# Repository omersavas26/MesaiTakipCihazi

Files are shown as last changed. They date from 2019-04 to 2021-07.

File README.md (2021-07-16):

# Mesai Takip Cihazı
## Kütahya İl Özel İdaresi - Bilgi işlem müdürlüğü

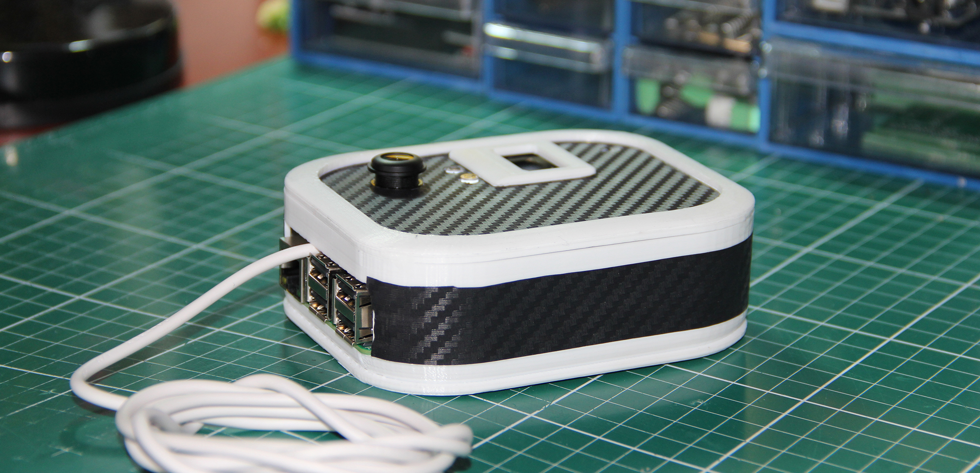
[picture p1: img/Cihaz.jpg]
Cihaz


Kütahya İl Özel İdaresi için geliştirmiş olduğumuz mesai takip cihazıdır. Yazılımı, devre tasarımı ve (3d yazdırılabilir) kutu tasarımı tamamen bize aittir. Tüm Raspberry Pi sürümleri ile çalışmaktadır. Fakat kutu RP3 için tasarlandığından diğer sürümleri için revizyon gerekir.

Cihazın açılması ile "main.py" yazılımı çalışır ve kart okutulması için beklemeye başlar. Başlatılması esnasında "./auth.py" dosyasını ve "./updateUsersList.py" dosyasını tetikleyerek cihaza özel güncel bir yetki alımasını ve bu yetkiyi kullanarak güncel kullanıcı listesinin alınmasını tetikler. Kullanıcı listesi personelin sunucu iletişimi esnasında bekletilmemesini sağlar. Personel kart okuttuğunda ilk olarak kameradan fotoğrafını alır, sonra ses ve ışık ile sinyal verir. Eğer okutulan kart id numarası "./file/users.json" dosyasında (bkz: "updateUserList.py") kayıtlı ise ekrana personel ismini yazar ver personeli bekletmeden gönderir. Sonra asenkron olarak sunucuya kart okutma bilgisini içeren bir istek atar cevap olarak da bir id numarası bekler. Cevap alabilirse çektiği fotoğrafın adını bu id bilgisi ile değiştirir. Eğer okutulan kart id numarası "./file/users.json" dosyasında yok ise sunucuya senkron bir istek atarak kart okutulma bilgisini gönderir cevap olarak de personel adı ve kart okutma için bir id numarası bekler. Beklediği cevap gelirse çektiği resmin adını yine id numarası ile değiştirerek personel adını ekrana yazdırır. Her ihtimal için; eğer beklenen cevap gelmez ise resmin adını card id ve tarih saat bilgisi olarak bırakır (bkz: "send.py"). Bir sonraki personelin kart okutmasını beklemeye başlar.

Eğer istenir ise, her kart okutmada bir kapı yada turnike tetiklenebilir. Ayrıca sunucu bağlantısı olmadan "./file/users.json" dosyasını manuel olarak doldurarak offline olarak da kullanılabilir.

Cihaz, personel geçişini yavaşlatmamak ve bağlantı olmadığı zamanlarda mesai takibini aksatmamak için çektği fotoğrafları önce hafızasında biriktirir sonra sizin belirlediğiniz peryotlarda sunucuya yüklemeye çalışır (bkz: "send.py"). Fotoğraflar "./foto" dizinindedir. İki tip fotoğraf vardır. İlki; sorunsuz bir şekilde sunucuya kart okutma bilgisi gönderilmiş ve cevap olarak da eklenen kaydın id bilgisi geri dönmüş olan fotoğraflar. Bunların isimleri "ID146589_XXXXX.jpg" şeklindedir. "_" karakterinden sonraki "XXXXXX" dizisi opsiyoneldir. Sunucu tarafından her kayıt için özel bir token gönderilir ise bu "XXXXXX" yerine yazılır. Böylelikle kayıt ikinci bir token ile korunmuş olur. Token bilgisini bilmeyen bir cihaz, fotoğraf yükleme yapamaz. İkinci tip fotoğraflar ise "TN198 76 64 27-2021_04_01_16_58_00.jpg" şeklinde isimlendirilmiştir. Bunlar, kart okutma bilgisi sunucuya gönderilememiş geçişler için çekilmiş olan fotoğraflardır. Adında kart bilgisi ve geçiş zamanını tutar. "send.py" yazılımı belirli peryotlarda çalışarak önce kayıt id 'leri olmayanları sunucuya kart okutma bilgisi oalrak gönderir ve id talep eder; ardından tüm fotoğrafları band genişliğini sınırlandırarak sunucuya yükler.

Sahadaki çok sayıda cihazınızın güncellenmesi için bir mekanizma kurulmuştur. Cihazlar belirli aralıklarda sizin belirdiğiniz adresi kontrol ederek güncel dosyaları otomatik olarak alabilirler (bkz "update.py"). İstenirse bu adres token ile korunabilir. Bu sayede yazılımın yanı sıra font ve logo gibi bilgilerde uzaktan değiştirilebilir.

Cihaz kameranın bir özelliği olarak 135 derece oval fotoğraf almaktadır. Ayrıca yine kameranın bir özelliği olarak karanlık ortamlarda da -gece görüşü- fotoğraf alabilmektedir. 13.56 Mhz mifare rfid kart ile uyumludur.

### auth.py
Eğer token auth ile çalışan bir servisiniz varsa bu dosya çalıştığında servisinize login isteği atar. Login olundu ise token ve cihaz ismi gibi bilgilerden "./file/auth.json" adında bir yetki dosyası oluşturur. "main.py" ve "send.py" gibi dosyalar ilk çalıştıklarında bu dosyayı tetikleyerek auth işlemi gerçekleştirirler ve çalışma süreleri boyunca auth.json dosyasını kullanırlar. Ayrıca cihaz ilk açıldığında da tetiklenir. Eğer cihaz yetkilendirmesi yapmak istenmiyorsa cihaz adı gibi bilgileri içeren sabit bir auth.json dosyası oluşturulabilir.

### clear.py
Cihaz ilk açıldığında çalışarak GPIO pin çıkışlarını temizler.

### control.py
cron ile her dakika çalışarak "main.py" nin çalışıyor olması gibi kontrol edilmesi gereken süreçleri izler. Sorun var ise yeniden başlatır.

### dateTimeSync.py 
Kısıtlı ağlarda cihaz tarih saat servisine erişierek zaman bilgisi alamaz ise bir http servis üzerinden tarih saat bilgisi alınarak cihazın zamanını günceller.

### fileList.txt
Bu dosya güncelleme sunucusu üzerinde bulunur. "update.py" yazılımı önce uzaktaki "version.txt" dosyasına sonra da bu dosyaya bakarak güncellemesi gereken dosyaları belirler ve güncel dosyaları indirerek cihaz üzerinde yazar. Yazılım mekanizmasına yeni bir dosya eklendi ise dosya adı ve yolu fileList.txt içine yazılmalıdır. 

### main.py
Ana yazılımdır. Cihaz ilk açıldığında çalışmaya başlar ve kapanana kadar çalışarak personelin kart okutmasını bekler. Kart okutulması ile fotoğraf çeker ve sunucu bu kart okutulması hakkında bilgilendirir. Başlatılması esnasında "./auth.py" dosyasını ve "./updateUsersList.py" dosyasını tetikleyerek cihaza özel güncel bir yetki alımasını ve (eğer gerekiyorsa) bu yetkiyi kullanarak güncel kullanıcı listesinin alınmasını tetikler.

### send.py
"./main.py" tarafından üretilmiş olan fotoğrafları belirli aralıklara sunucuya yüklemeye çalışır. Başlatılması esnasında "./auth.py" dosyasını tetikler ve (eğer gerekiyorsa) sunucu iletişimi sırasında bu yetki bilgisini kullanır.

### update.py
Belirli aralıklarla güncelleme sunucusuna talepler göndererek gülcel bir sürüm var ise cihaz yazılımını günceller.

### updateUserList.py
Sunucudan güncel kullanıcı bilgisini ister ve "./file/users.json" dosyasını doldurur. İstenirse users.json dosyası manuel olarak doldurularak cihaz offline olarak da kullanılabilir.

### version.txt
Aynı anda hem cihazda hemde güncelleme sunucusunda bulunur. "./update.py" bu dosyaya bakarak, sunucu üzerindeki dosyadan farklı ise güncelleme yapar.

### lib/helper.py
Tüm jenerik methodları içerir.

### lib/variables.py
Backend servisleri ve cihazın çalışması ile alakalı ayarları içeren dosyadır. Cihazı "senkron çalışmaya zorla" yada yemekhane gibi konumlarda kullanmak için "otantike olamayan kullanıcıya röleyi tetikleme" gibi ayarları yapabilmenizi sağlar. Ayarlarınız güncelleme gelse bile değişmesin isterseniz aynı dizine "localVariables.py" dosyası ile özel ayarlarınızı yazarsınız. 

### lib/test[*].py
Test scriptleri

## Bileşenler
 1. Raspberry Pi (3 B+ önerilir)
 2. Mikro SD kart
 3. Raspberry Pi Camera (Raspberry Pi 3 Model B + Night Vision Camera 5MP Wide Angle 135 Degree Fisheye Lens 1080P Camera Module)
 4. PCB Devre
 5. SSD 1306 Oled LCD ekran (128*64)
 6. RFID-RC522 rfid kart okuyucu
 7. Kırmızı ve yeşil kesik baş led
 8. 5V mini usb adaptor ve kablo
 9. Tek kanal 5v röle kartı (Opsiyonel)
 10. 3D yazdırılmış kutu parçaları
 11. Kaplama için yeteri kadar karbon folyo (Opsiyonel)
 12. 4 adet 2.2x6 mm ve 3 adet 2.2x9 mm vida
 13. 13x2, 4x1, 8x1 dişi header 
 14. Buzzer

## Donanım

[Video gelecek]

## Yazılım

1. Image ile kurulum
.img dosyası indirilip micro sd karta "Win32 Disk Imager" yada benzeri bir uygulama ile yazılıp 

2. Manuel kurulum
   - Arduino klasorundeki buzzer.ino dosyası Arduino nanoya upload edilir.
   - Raspbian işletim sistemi sd karta yüklenir ve açılır
   - `sudo raspi-config` ile ayar ekranı açılıp  ssh, camera, i2c ve spi aktifleştirilir
   - Aşağıdaki kurulumlar yapılır.
   
    ```
    sudo apt-get update
    sudo apt-get upgrade

    sudo apt-get install git python3 python3-spidev python3-dev python3-pip python3-smbus  python3-picamera i2c-tools wondershaper libopenjp2-7 -y
	
	sudo python3 -m pip install -U pip
	sudo python3 -m pip install -U setuptools
	
	sudo pip3 install Pillow
	sudo pip3 install adafruit-circuitpython-ssd1306
	sudo pip3 install requests
	
    sudo chmod 777 -R /var/www/html/
	
	git clone https://github.com/lthiery/SPI-Py.git && cd SPI-Py && git checkout 8cce26b9ee6e69eb041e9d5665944b88688fca68 && sudo python3 setup.py install	
    ```
	
   - `sudo crontab -e` ile zamanlanmış görevler açılıp en alta aşağıdaki satırlar eklenir.
   .
    ```	
	@reboot python3 /var/www/html/clear.py &

	@reboot python3 /var/www/html/dateTimeSync.py &
	0 * * * * python3 /var/www/html/dateTimeSync.py &

	@reboot sleep 10 && python3 /var/www/html/main.py

	0 */2 * * * python3 /var/www/html/send.py &

	0 12 * * * python3 /var/www/html/update.py

	0 13 * * * python3 /var/www/html/updateUsersList.py &

	* * * * * python3 /var/www/html/control.py &

	30 22 * * *     /sbin/shutdown -r +1 &
    ```
	
   - wget download.sh && ./download.sh 

## Yapılacaklar

1. Versiyon 3 'de oled arduino ile sürülecek, bu sayede raspberry pi açılana kadar ekranda bilgi mesajı basılacak.
2. Arduino nano yerine arduino mikro kullanılacak
3. Anlık enerji düşmesini engellemek için kondansatör koyulacak

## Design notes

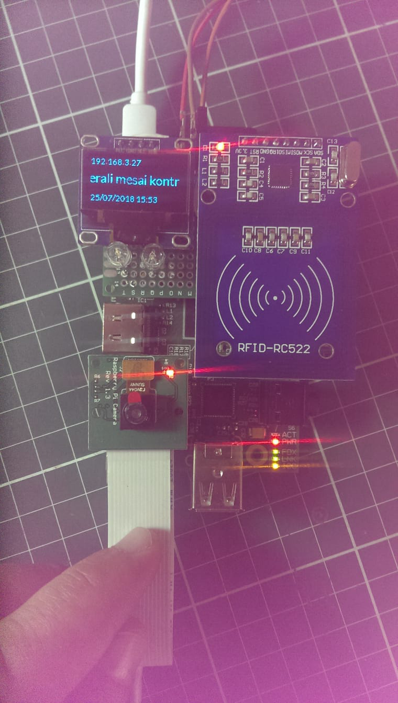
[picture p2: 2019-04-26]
img/Tasarım.jpeg

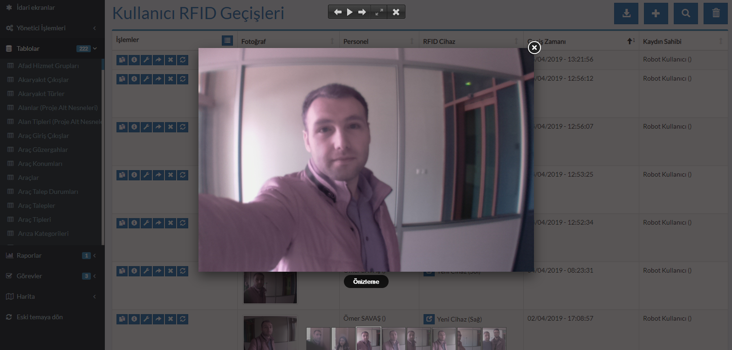
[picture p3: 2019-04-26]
img/Fotograf.png

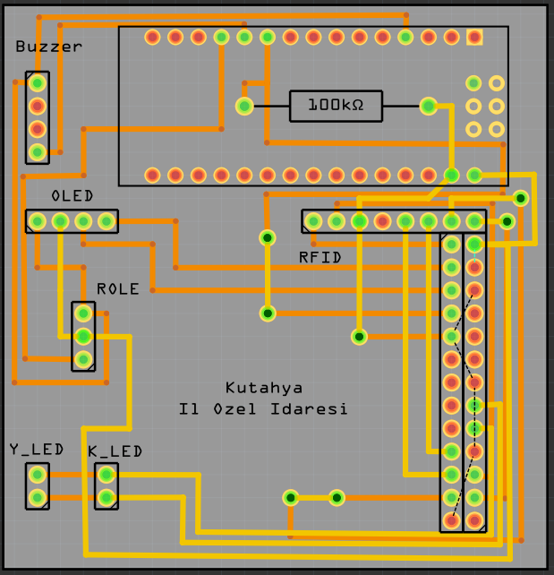
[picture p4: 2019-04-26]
circuit/devre.png

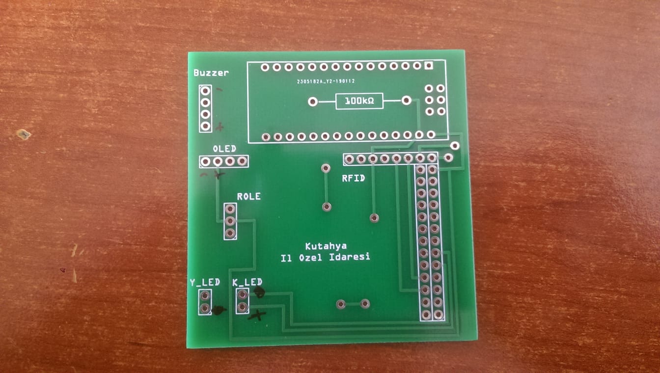
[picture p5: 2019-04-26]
circuit/Pcb.jpeg

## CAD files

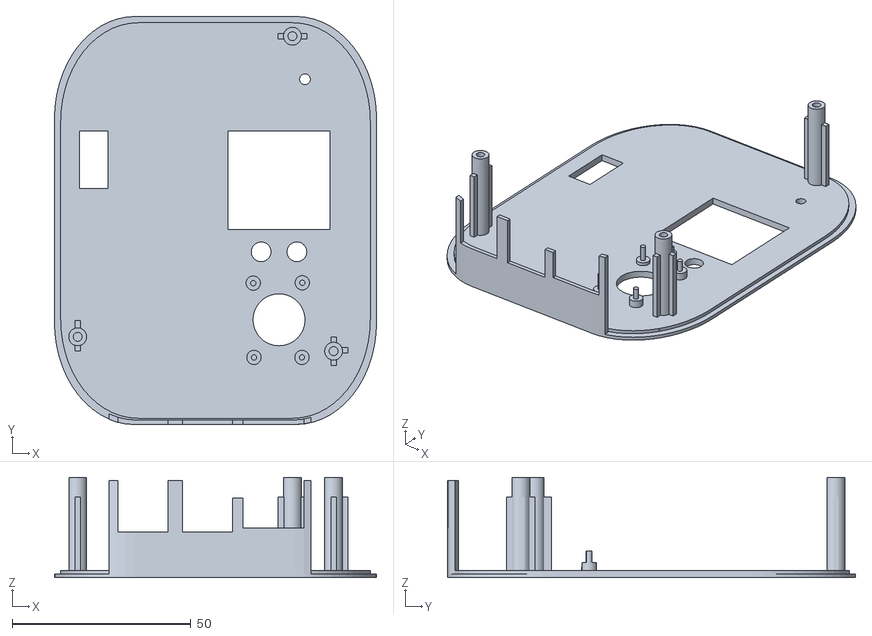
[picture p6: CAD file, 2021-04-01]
box/cover.stl
90.0 x 114.0 x 28.0

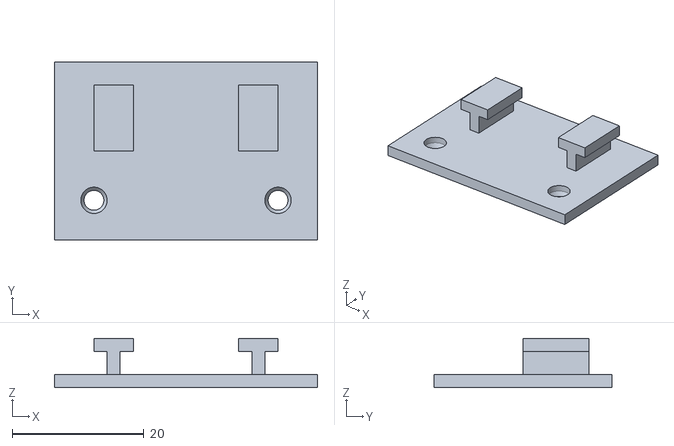
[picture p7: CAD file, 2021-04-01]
box/suspension.stl
40.0 x 27.0 x 7.50

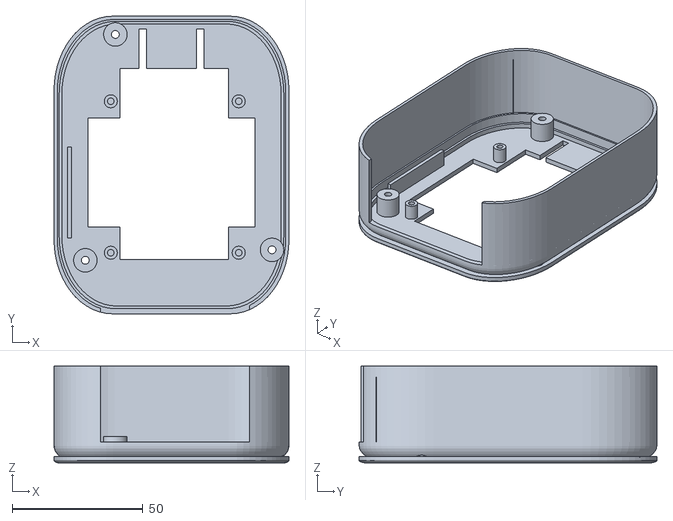
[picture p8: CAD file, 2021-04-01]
box/box.stl
90.0 x 114.0 x 37.0

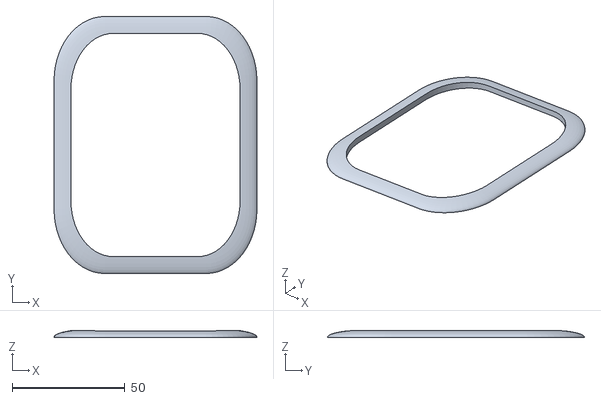
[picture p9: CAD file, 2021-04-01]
box/frame.stl
90.0 x 114.0 x 3.22

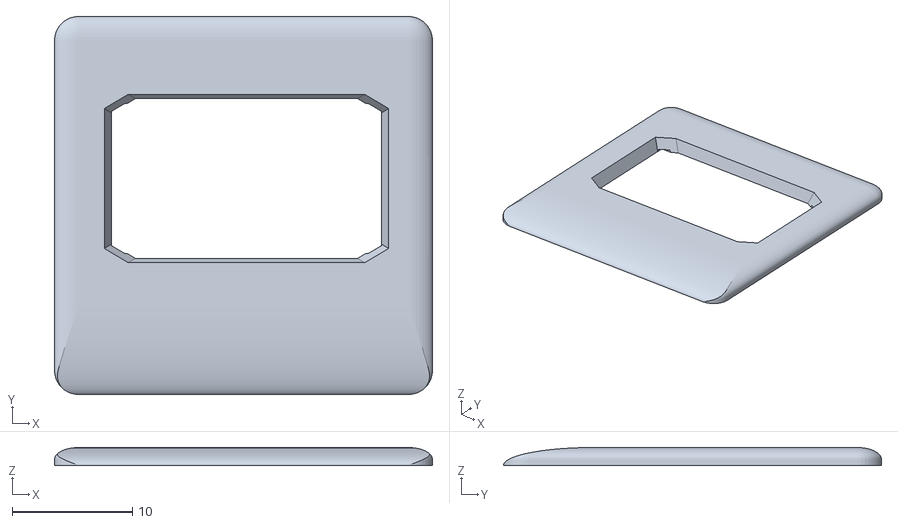
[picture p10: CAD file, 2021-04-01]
box/window.stl
31.5 x 31.5 x 1.50

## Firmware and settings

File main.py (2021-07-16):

##@reboot sleep 10 && python3 /var/www/html/main.py & 
##2021-07-16 12:00:00

import os 
import sys
import time
import datetime
import traceback

import RPi.GPIO as GPIO

sys.path.append("/var/www/html/lib/")
from helper import *
import helper as h

file_name = os.path.basename(__file__)



buzzer_pin = 4 #buzzer_pin = 7  //7. bacak GPIO4
red_led = 23#red_led = 16
green_led = 24#green_led = 18
triger_pin = 17#triger_pin = 11

display_scene_timer_period = 15.0
display_using = False
current_scene = -1
scenes = []

read_rfid_timer_period = 0.25	
local_last_rfid_card_id = ""

last_rfid_card_id_remember_timeout = 75.0
local_debug = False

sendPhotoForever = False

tanimsiz_kullanici_ad = "Tan\u0131ms\u0131z"
tanimsiz_kullanici_soyad = "Kullan\u0131c\u0131"

try:
	def clear_pins():
		global buzzer_pin, red_led, green_led, triger_pin
		
		pin_off(buzzer_pin)
		pin_off(red_led)
		pin_off(green_led)
		pin_off(triger_pin)
		
	def on_load():
		log_and_run(write_logo_on_display)
		
		log_and_run(clear_pins)
		
		log_and_run(set_cam)		
		
		temp = log_and_run(fill_auth, True)
		if temp == True:
			temp = log_and_run(fill_users, True)
		else:
			log_and_run(fill_users)
		
		if temp == False:
			log(INFO, "Users or Auth was failed")
			h.connected = False
		else:		
			h.connected = True
			
		log_and_run(connection_control)
		
		log_and_run(fill_scene)
		
	def set_cam():
		h.camera.rotation = 90
		h.camera.resolution = (1024, 768)
		
	def fill_scene():
		global scenes
		
		scenes.append(scene_1)
		scenes.append(scene_2)
		scenes.append(scene_3)
		scenes.append(logo_scene)
		
	def logo_scene():
		global current_scene, display_using
		control_index = 3
		seq = -1
		
		while True:
			if h.loop == False:
				break;
				
			if current_scene != control_index:
				break;
			
			waited = False 
			
			while display_using:
				log(INFO, "Display using.")
				waited = True
				time.sleep(1)
			
			if waited:
				log_and_run(clear_display)
			
			if seq != h.display_clear_seq:
				seq = h.display_clear_seq
				
				log_and_run(write_logo_on_display)
			
			time.sleep(0.3)
		
		
	def get_now_info_for_display():
		now = datetime.datetime.now()
			
		temp = str(now.strftime("%d aaa %H:%M:%S"));
		temp = temp.replace("aaa", h.months[now.month-1])
		
		temp = temp.split(" ")
		
		d = temp[0]+" "+temp[1]
		t = temp[2]
		return (d, t)
		
	def place_holder_date_time(params = None):
		
		if params == None:
			(d, t) = log_and_run(get_now_info_for_display)
			params = {
				"d": d,
				"t": t
			}
		
		write_text_on_display(params["d"], font_size = 16)
		write_text_on_display(params["t"], x=87, font_size = 16)
		
		return params
		
		
		
	def place_holder_auth_name(params = None):		
		if params == None:
		
			if h.auth == None:
				text = "Yetkisiz Cihaz - Yetkisiz Cihaz ";
			else:
				text = h.auth["name"] + " - " + h.auth["name"]
			
			params = {
				"sizes": [0, 0, 0, 0],
				"text": text,
				"current_x": 10
			}
			
		clean_area_on_display(params["sizes"])
		params["sizes"] = write_text_on_display(params["text"], x = params["current_x"], y = 22, font_size = 36)
		
		params["current_x"] = params["current_x"] - 7
		
		return params		
		
		
	def scene_1(current_x = 10):	
		scene_base(0, False, place_holder_date_time, place_holder_auth_name, 0.05)
		
	def get_real_local_ip():
		ips = get_ip_adresses()
		
		ip = "-"
		for i in range(len(ips)):
			if ips[i].find("127.0") > -1:
				continue
				
			ip = ips[i]
			break
			
		return ip
				
	def place_holder_no_connection(params = None):
		global oled_data
				
		ip = log_and_run(get_real_local_ip) 
		
		write_text_on_display("Internet", x = 18, y = 0, font_size = 24)
		write_text_on_display("Yok", x=42, y=25, font_size = 22)		
		write_text_on_center_of_display(ip, y = 48, font_size = 16)
	
	def scene_2():	
		scene_base(1, h.connected, place_holder_no_connection)
		
	def place_holder_no_auth(params = None):
		write_text_on_display("Yetkisiz", x = 10, y = 5, font_size = 28)
		write_text_on_display("Cihaz", x=25, y=32, font_size = 28)

	def scene_3():		
		scene_base(2, h.auth != None, place_holder_no_auth)
		
		
	def scene_base(control_index, next_scene_control, writing_function_on_clear, writing_function_forewer = None, loop_period = 0.3):
		global current_scene, display_using, local_debug
		
		if next_scene_control:
			current_scene = current_scene + 1
			if current_scene == len(scenes):
				current_scene = 0
				
			log_and_run_async(scenes[current_scene])	
			return
		
		seq = -1
				
		h.debug = False
		params1 = None
		params2 = None
		while True:
			if h.loop == False:
				break;
				
			if current_scene != control_index:
				break;
			
			waited = False 
			
			while display_using:
				log(INFO, "Display using")
				waited = True
				time.sleep(1)
			
			if waited:
				log_and_run(clear_display)
			
			if seq != h.display_clear_seq:
				seq = h.display_clear_seq
				
				params1 = log_and_run(writing_function_on_clear, params1)
				
			if writing_function_forewer != None:
				params2 = log_and_run(writing_function_forewer, params2)
			
			time.sleep(loop_period)
			
		h.debug = local_debug
			
	def run():
		log_and_run_async(update_display_scene)
		
		log_and_run(read_rfid)
		
	def update_display_scene():
		global display_scene_timer_period, current_scene, scenes, display_using
		
		temp = threading.Timer(display_scene_timer_period, update_display_scene)
		temp.daemon = True
		temp.start()
				
		current_scene = current_scene + 1
		if current_scene == len(scenes):
			current_scene = 0
				
		try:
			while display_using:
				log(INFO, "Display using..")
				time.sleep(0.3)
				
			log_and_run(clear_display)
			log_and_run(scenes[current_scene])
		except Exception as e:
			log_e(e, "update_display_scene error")
				
	def wait_message():
		log_and_run(clear_display)
		write_text_on_display("Bekleyin...", x=0, y=22, font_size = 26)
		
	def show_rfid_same_card_message_on_display():
		global red_led, display_using
		
		display_using = True		
		time.sleep(0.3)
		
		pin_on(red_led, time_out = 1)		
		pin_on(buzzer_pin, time_out = 0.05)
		
		log_and_run(clear_display)
				
		write_text_on_display("Bu kart", x = 24, y = 0, font_size = 22)
		write_text_on_display("az once", x = 24, y = 21, font_size = 22)
		write_text_on_display("okutldu!", x = 20, y = 42, font_size = 22)
		
		time.sleep(1)
		
		display_using = False

	def show_ip_on_display():
		global display_using 
		
		display_using = True
		time.sleep(0.3)
		
		ip = log_and_run(get_real_local_ip) 
		log_and_run(clear_display)
		write_text_on_center_of_display(ip, font_size = 16, direction = "xy")
		time.sleep(5);
		
		display_using = False
		
	def toggle_send_photo_forever():
		global sendPhotoForever, display_using
		
		display_using = True
		time.sleep(0.3)
		
		log_and_run(clear_display)
		
		if sendPhotoForever:
			write_text_on_center_of_display("Hemen aktar iptal", font_size = 16, direction = "xy")
			sendPhotoForever = False
		else:
			write_text_on_center_of_display("Hemen aktar acik", font_size = 16, direction = "xy")
			sendPhotoForever = True
		
		time.sleep(3)
		display_using = False
		
	def send_photo(file):
		global display_using
		
		temp = file.replace(".jpg", "")[2:].split("_")
		id = temp[0]
		record_token = temp[1]
		
		url = get_url_for_send_photo()
				
		params = { "id": id, "record_token": record_token }
		files = {'fotograf[]': open(h.base_photo_path+file, 'rb')}
		
		data = http_post(url, data = params, files = files, j = True)
		
		if data != None:
			if data["status"] == "success":
				os.remove(h.base_photo_path+file)
				display_message("Hemen aktar ok", time_out=3)	
			else:
				display_message("Hemen aktar hata.", time_out=3)				
		else:
			display_message("Hemen aktar hata", time_out=3)		
			
	def display_message(msg, time_out = 1):
		global display_using
		
		log(INFO, "Display msg: " + msg) 
		
		display_using = True
		time.sleep(0.3)
		
		log_and_run(clear_display)
		write_text_on_center_of_display(msg, font_size = 16, direction = "xy")
		time.sleep(time_out)
		display_using = False
				
	def same_rfid_read():
		global display_using
							
		if h.rfid_same_count == 4:
			log(INFO, "show_ip_on_display will start")
			log_and_run(show_ip_on_display)
		if h.rfid_same_count == 6:
			log(INFO, "toggle_send_photo_forever will start")
			log_and_run(toggle_send_photo_forever)
		elif h.rfid_same_count == 8:
			display_using = False
			log_and_run(reboot_os)
			return			
			
	def rfid_readed_request_async(card_id, photo_name):
		global sendPhotoForever
		
		url = get_url_for_rfid_readed(card_id)
		if url == "":
			log(WARNING, "rfid_readed_request_async by pass")
			return
			
		data = http_get(url, j=True)
		if data != None and data["status"] == "success":
			new_name = "ID"+str(data["data"]["user"]["id"])+"_"+data["data"]["user"]["record_token"]+".jpg"
			os.rename(h.base_photo_path + photo_name, h.base_photo_path + new_name)
			log(INFO, "rfid_readed_request_async OK")
			
			if sendPhotoForever:
				log_and_run(send_photo, new_name)
			
		else:
			log(WARNING, "rfid_readed_request_async by pass (data)")
			
	def rfid_readed_request(params):
		global sendPhotoForever, tanimsiz_kullanici_ad, tanimsiz_kullanici_soyad
				
		try:
			url = get_url_for_rfid_readed(params["card_id"])
			if url == "":
				log(WARNING, "rfid_readed_request by pass")
				return (tanimsiz_kullanici_ad, tanimsiz_kullanici_soyad)
				
			log_and_run(unlimit_bandwith)
			data = http_get(url, j=True)
			if data != None and data["status"] == "success":
				new_name = "ID"+str(data["data"]["user"]["id"])+"_"+data["data"]["user"]["record_token"]+".jpg"
				os.rename(h.base_photo_path + params["photo_name"], h.base_photo_path + new_name)
				
				if sendPhotoForever:
					log_and_run_async(send_photo, [new_name])
				
				log(INFO, "rfid_readed_request OK")
				
				if data["data"]["user"]["name"] == None:
					data["data"]["user"]["name"] = tanimsiz_kullanici_ad
					data["data"]["user"]["surname"] = tanimsiz_kullanici_soyad
					
				return (data["data"]["user"]["name"], data["data"]["user"]["surname"])
				
			else:
				log(WARNING, "rfid_readed_request by pass (data)")
				return (t, k)
				
		except Exception as e:
			log_e(e, "read_rfid rfid_readed_request")
			return (t, k)
			
	def clear_local_last_rfid_card_id():
		global local_last_rfid_card_id, local_debug
		
		temp = h.debug
		if local_debug:
			h.debug = True
		
		log(INFO, "clear_local_last_rfid_card_id running...")
		local_last_rfid_card_id = ""
		log(INFO, "clear_local_last_rfid_card_id OK")
		
		if local_debug:
			h.debug = temp
				
	def read_rfid():
		global green_led, display_using, read_rfid_timer_period, local_last_rfid_card_id, local_debug, same_rfid_read_control, last_rfid_card_id_remember_timeout, rfid_read_mode_async, relay_only_true_user, tanimsiz_kullanici_ad, tanimsiz_kullanici_soyad
		
		while True:
			if h.loop == False: break
			
			try:	
				card_id = get_card_id_from_rfid()
				if card_id != None:
					
					h.debug = local_debug
										
					now = str(datetime.datetime.now().strftime("%Y_%m_%d_%H_%M_%S"))
					photo_name = "TN"+card_id+"-"+now+".jpg"
					log_and_run_async(take_photo, [photo_name])
					
					display_using = True
					
					if local_last_rfid_card_id == card_id:
						log_and_run(same_rfid_read)
						
						
					if same_rfid_read_control and local_last_rfid_card_id == card_id:
						log_and_run(show_rfid_same_card_message_on_display)
					else:	
						if relay_only_true_user == False:
							pin_on(green_led, 1)
						
						local_last_rfid_card_id = card_id
						
						temp = threading.Timer(last_rfid_card_id_remember_timeout, clear_local_last_rfid_card_id)
						temp.daemon = True
						temp.start()						
						
						if relay_only_true_user == False:
							pin_on(buzzer_pin, time_out = 0.05)
							pin_on(triger_pin, time_out = 0.05)
						
						if rfid_read_mode_async and card_id in h.users:						
							log_and_run_async(rfid_readed_request_async, [card_id, photo_name])	
							name = h.users[card_id]["name"]
							surname = h.users[card_id]["surname"]
						else:
							log_and_run(wait_message)
							
							(name, surname) = log_and_run(rfid_readed_request, {"card_id": card_id, "photo_name": photo_name})
							
							if name != tanimsiz_kullanici_ad and surname != tanimsiz_kullanici_soyad and relay_only_true_user:
								pin_on(green_led, 1)
								pin_on(buzzer_pin, time_out = 0.05)
								pin_on(triger_pin, time_out = 0.05)
							elif rfid_read_mode_async == False:
								pin_on(red_led, 1)
							
						log_and_run(clear_display)
						
						write_text_on_center_of_display(name, y = 2, font_size = 20)
						write_text_on_center_of_display(surname, y = 25, font_size = 20)
						
						temp = str(datetime.datetime.now().strftime("%H:%M"))
						write_text_on_center_of_display(temp, y = 45, font_size = 20)
						
						time.sleep(1)
											
					display_using = False
					h.debug = False

			except Exception as e:
				display_using = False
				log_e(e, "read_rfid error")
			
			time.sleep(read_rfid_timer_period)
		
		

	#Ana Fonksiyon
	if __name__ == "__main__":	
				
		time.sleep(1)
		
		h.restart = True
		h.loop = True
		h.debug = local_debug;
		
		pin_config = {"in": [], "out": [buzzer_pin, red_led, green_led, triger_pin]}
		
		preload(file_name, online = False, disp = "oled", cam = True, rf = True, pins = pin_config) 
		
		log_and_run(on_load)
		
		log_and_run(run)
						
		log_and_run(endload)


		
except Exception as e:
	fn = os.path.basename(__file__)		
	root_ex(fn, e)

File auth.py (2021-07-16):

#@reboot python3 /var/www/html/auth.py &
import os 
import sys
import json
import traceback

sys.path.append("/var/www/html/lib/")
from helper import *
import helper as h

file_name = os.path.basename(__file__)



try:
	def read_ssh_key():
		data = read_from_file("/root/.ssh/id_rsa.pub")
		if data == None:
			cmd = 'ssh-keygen -b 2048 -t rsa -f /root/.ssh/id_rsa -q -N ""'
			command(cmd)
			data = read_from_file("/root/.ssh/id_rsa.pub")
			
			if data == None:
				return None
			
		return data.strip('\n')
	
	def get_device_unique():
		ssh_key = log_and_run(read_ssh_key)
		params ={ 'ssh_anahtar': ssh_key }
		
		url = log_and_run(get_url_for_deg_device_key)
		data = http_post(url, data=params, j=True)
		if data == None:
			log(ERROR, "Yeni anahtar alinamadi! (data: None, "+to_json_str(params)+")")
			return ""
			
		if data["status"] != "success":
			log(ERROR, "Yeni anahtar alinamadi! (data: "+to_json_str(data)+", params: "+to_json_str(params)+")")
			return ""
			
		key = data["data"]["message"]
		
		macs = log_and_run(get_mac_adresses)		
		serial = log_and_run(get_cpu_serial)
		
		return macs[0] + serial + macs[1] + key
		
	def get_auth():
		global device_table_name
				
		unique = log_and_run(get_device_unique)
		if unique == "": 
			return ""
			
		params = {
			"type": device_table_name,
			"unique": unique
		}
		
		data = http_post(api_base_url+"deviceLogin", data=params, j=True)
		if data == None:
			log(ERROR, "Auth data alinamadi! (data: None, params: "+to_json_str(params)+")")
			return ""
		
		if data["status"] != "success":
			log(ERROR, "Auth data alinamadi! (data: "+to_json_str(data)+", params: "+to_json_str(params)+" )")
			return ""
				
		return data["data"]
		
	def run():
		auth = log_and_run(get_auth)
		if auth != "":						
			data = {
				"token": auth["token"],
				"id": auth["device"]["id"]
			}
			
			try:
				data["name"] = auth["device"]["name"]
			except Exception as e:
				data["name"] = auth["device"]["name_basic"]
						
			write_to_file(h.auth_file_path, data, j = True)
		else:
			log_and_run(add_as_new_device)
			
	def add_as_new_device():
		global api_base_url, new_device_column_set_id
	
		ips = log_and_run(get_ip_adresses)		
		macs = log_and_run(get_mac_adresses)		
		serial = log_and_run(get_cpu_serial)
		unique = log_and_run(get_device_unique)
		real_ip = log_and_run(get_real_ip)
		cihaz_json = read_from_file("/var/www/html/cihaz.json")
		ssh_key = log_and_run(read_ssh_key)
		
		
		detail = {
			"ips": ips,
			"macs": macs,
			"serial": serial,
			"unique": unique,
			"real_ip": real_ip,
			"cihaz_json": cihaz_json,
			"ssh_key": ssh_key
		}
		
		params = {
			"column_set_id": new_device_column_set_id, 
			"detail": to_json_str(detail),
			"id": 0 
		}
		
		url = api_base_url+"public/tables/yeni_cihazlar/store"
		data = http_post(url, data=params, j=True)
		
		if data == None:
			log(ERROR, "Yeni cihaz olarak eklenemedi! (data: None, params: "+to_json_str(params)+")")
			return ""
		
		if data["status"] != "success":
			log(ERROR, "Yeni cihaz olarak eklenemedi! (data: "+to_json_str(data)+", params: "+to_json_str(params)+" )")
			return
		

	
	#Ana Fonksiyon
	if __name__ == "__main__":		
		
		preload(file_name)
		
		log_and_run(run)
				
		log_and_run(endload)


		
except Exception as e:
	fn = os.path.basename(__file__)		
	root_ex(fn, e)

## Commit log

2019-04-26 ilk yukleme
    [Cerceve.stl, Kapak1.stl, Kapak2.stl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]
2020-11-10 kbs.version
    index.py iyileştirme
    guncelle.py ekleme
    aktar.py ekleme
    buzzer.ino iyileştirme
    [Aski.stl, Cerceve.stl, Kapak.stl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]
